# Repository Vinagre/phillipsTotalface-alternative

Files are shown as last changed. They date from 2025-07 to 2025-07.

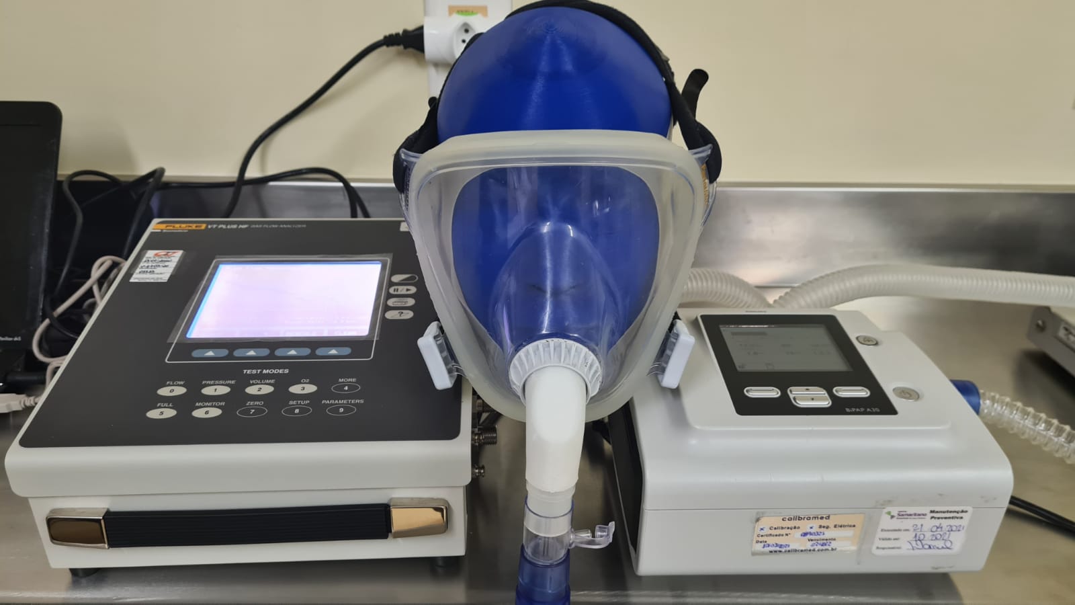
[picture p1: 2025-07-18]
images/test-setupo-02.jpeg

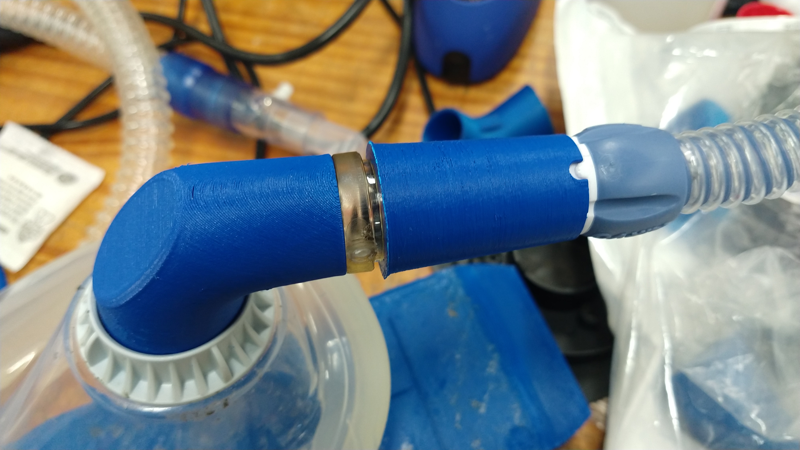
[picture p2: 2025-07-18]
images/testing.jpg

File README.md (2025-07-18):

 
# Manufatura Aditiva para Resiliência em Saúde  
# Additive Manufacturing for Healthcare Resilience

**Autores / Authors:**  
Raphael Vinagre, Marcelo Viana Marques Ferreira, João Victor Correia de Melo, Jorge Roberto Lopes

**Descrição / Description**  
Desenvolvimento, validação e documentação de dispositivos médicos impressos em 3D para ventilação não-invasiva em cenários de crise.  
Development, validation, and documentation of 3D-printed medical devices for non-invasive ventilation in crisis scenarios.

O projeto adota uma abordagem de design centrada no usuário e produção distribuída, promovendo resiliência hospitalar e manufatura aberta.  
The project adopts a human-centered design and distributed manufacturing, fostering hospital resilience and open manufacturing.

**Estrutura / Structure**
- `/stl/`: Arquivos STL das peças / STL 3D model files
- `/testes/`: Relatórios e dados experimentais / Test reports and raw data
- `/docs/`: Metodologia e fichas técnicas / Methodology and technical datasheets

**Licenciamento / Licensing**  
CC BY-SA 4.0. Consulte LICENSE / See LICENSE

---

Repositório bilíngue. Para informações detalhadas, consultar cada subdiretório.  
Bilingual repository. For detailed information, check each subdirectory.
=======
# phillipsTotalface-alternative
Development, validation, and documentation of 3D-printed medical devices for non-invasive ventilation in crisis scenarios. The project adopts a human-centered design approach and explores distributed production of critical components to enhance hospital resilience

# Manufatura Aditiva para Resiliência em Saúde  
# Additive Manufacturing for Healthcare Resilience

**Autores / Authors:**  
Raphael Vinagre, Marcelo Viana Marques Ferreira, João Victor Correia de Melo, Jorge Roberto Lopes

**Descrição / Description**  
Desenvolvimento, validação e documentação de dispositivos médicos impressos em 3D para ventilação não-invasiva em cenários de crise.  
Development, validation, and documentation of 3D-printed medical devices for non-invasive ventilation in crisis scenarios.

O projeto adota uma abordagem de design centrada no usuário e produção distribuída, promovendo resiliência hospitalar e manufatura aberta.  
The project adopts a human-centered design and distributed manufacturing, fostering hospital resilience and open manufacturing.

**Estrutura / Structure**
- `/stl/`: Arquivos STL das peças / STL 3D model files
- `/testes/`: Relatórios e dados experimentais / Test reports and raw data
- `/docs/`: Metodologia e fichas técnicas / Methodology and technical datasheets

**Licenciamento / Licensing**  
CC BY-SA 4.0. Consulte LICENSE / See LICENSE

---

Repositório bilíngue. Para informações detalhadas, consultar cada subdiretório.  
Bilingual repository. For detailed information, check each subdirectory.

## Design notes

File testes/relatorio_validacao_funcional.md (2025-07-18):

# Relatório de Validação Funcional  
# Functional Validation Report

**Autores / Authors:**  
Raphael Vinagre, Marcelo Viana Marques Ferreira, João Victor Correia de Melo, Jorge Roberto Lopes

## Amostragem / Sampling
- 30 unidades impressas (ABS) / 30 printed units (ABS)
- 10 unidades originais (controle, Philips) / 10 original units (control, Philips)

## Variáveis Testadas / Variables Tested
- Vedação / Seal integrity
- Resistência mecânica / Mechanical resistance
- Estabilidade dimensional pós-esterilização / Dimensional stability after sterilization

## Resultados / Results
- Diferença de pressão máxima: 2,1% (dentro da margem ISO 80601-2-12:2020)  
  Max pressure difference: 2.1% (within ISO 80601-2-12:2020 margin)
- Vedação equivalente em 98% dos testes  
  Equivalent sealing in 98% of tests
- Aceitação clínica: 100% na simulação  
  Clinical acceptance: 100% in simulation

*Detalhes quantitativos estão em `tabela_resultados.csv`.*  
*See `tabela_resultados.csv` for quantitative details.*

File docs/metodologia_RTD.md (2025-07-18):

# Metodologia Research Through Design (RTD)  
# Research Through Design (RTD) Methodology

**Autores / Authors:**  
Raphael Vinagre, Marcelo Viana Marques Ferreira, João Victor Correia de Melo, Jorge Roberto Lopes

## O que é RTD?  
A Research Through Design integra pesquisa e prática de projeto em ciclos iterativos, gerando soluções técnica e socialmente viáveis.  
Research Through Design (RTD) integrates research and design practice in iterative cycles, generating technically and socially viable solutions.

## Aplicação no projeto / Application in the project
- Imersão clínica / Clinical immersion
- Co-design interdisciplinar / Interdisciplinary co-design
- Prototipagem e testes iterativos / Iterative prototyping and testing
- Avaliação empírica e otimização final / Empirical evaluation and final optimization

*Veja documento principal para fluxograma detalhado.*  
*See main report for detailed flowchart.*

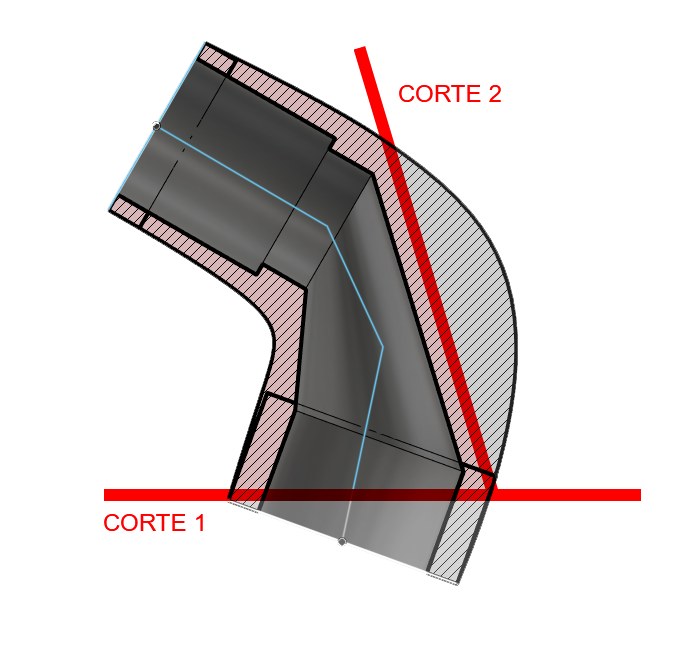
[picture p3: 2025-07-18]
images/cortes-peca.png

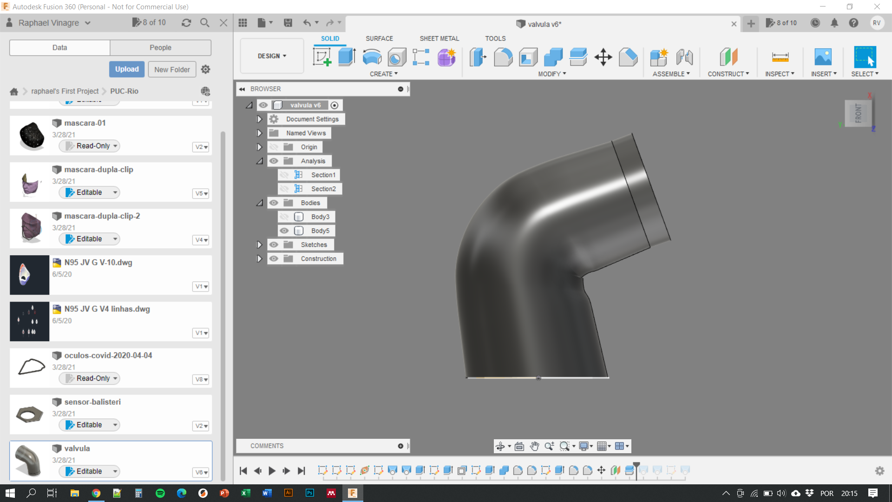
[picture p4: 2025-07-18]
images/fusion-drawing.png

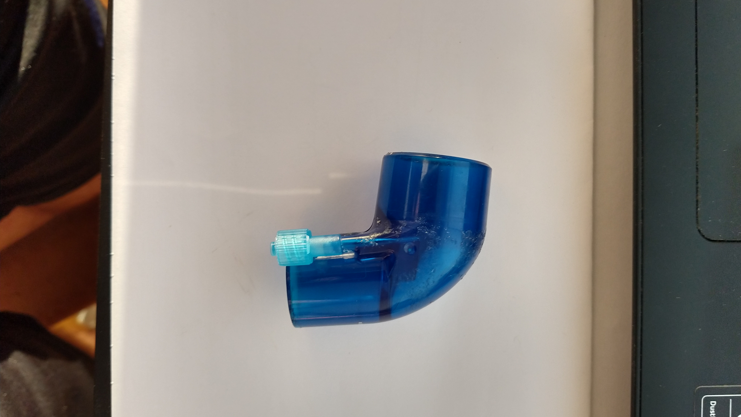
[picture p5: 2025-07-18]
images/IMG_20210326_170816761_HDR.jpg

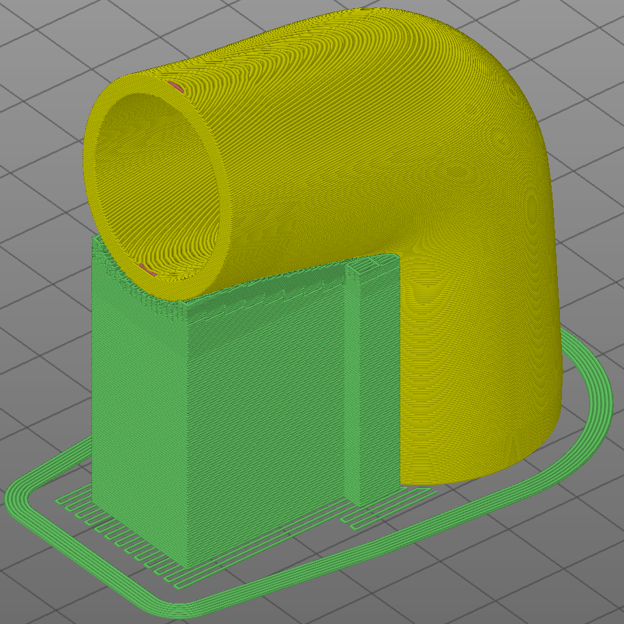
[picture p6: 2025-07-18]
images/suportes.png

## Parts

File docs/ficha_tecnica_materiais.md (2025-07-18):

# Ficha Técnica – Polímero ABS para Impressão 3D  
# ABS Polymer Technical Datasheet for 3D Printing

**Autores / Authors:**  
Raphael Vinagre, Marcelo Viana Marques Ferreira, João Victor Correia de Melo, Jorge Roberto Lopes

| Parâmetro | Valor (PT) | Value (EN) |
|---|---|---|
| Temp. bico | 220°C ± 5°C | Nozzle temp |
| Temp. mesa | 110°C ± 2°C | Bed temp |
| Velocidade impressão| 60 mm/s | Print speed |
| Esp. parede | 1,6 mm | Wall thickness |
| Altura de camada | 0,2 mm | Layer height |
| Preenchimento | 100% | Infill |
| Resfriamento | Desligado | Cooling off |

**Observação / Note:**  
ABS recomendado pela estabilidade após esterilização em vapor e peróxido.  
ABS is recommended due to its stability after vapor and hydrogen peroxide sterilization.

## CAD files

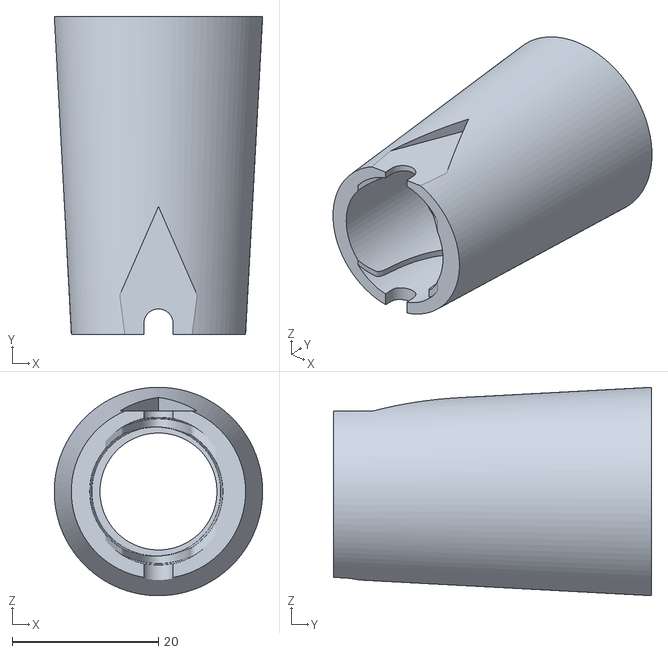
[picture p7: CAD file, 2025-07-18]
stl/encaixe-universalx-v5.stl
28.5 x 43.5 x 28.5

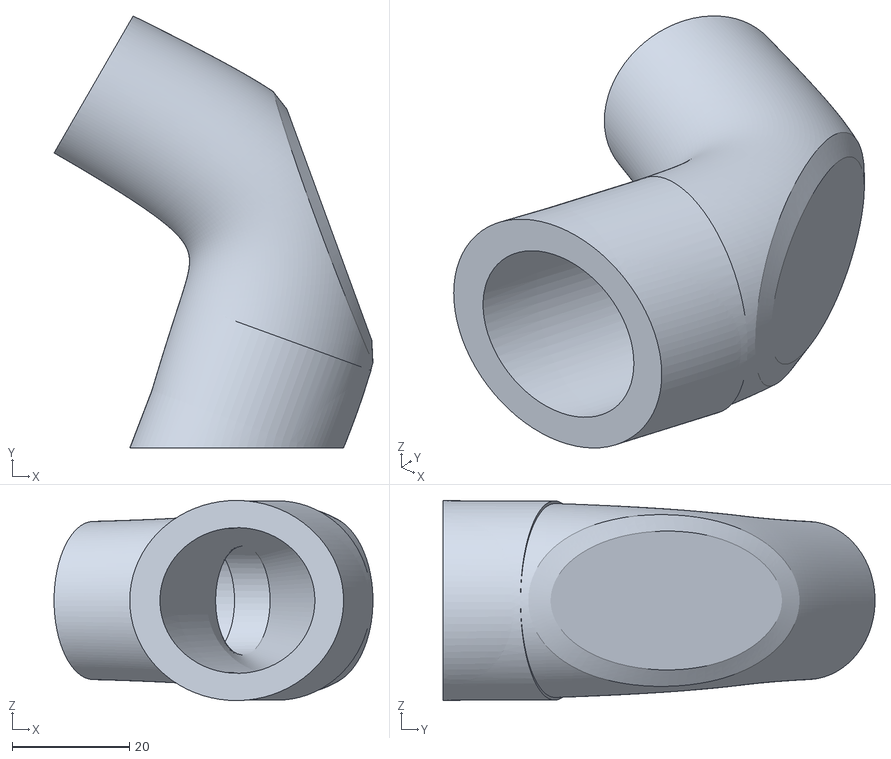
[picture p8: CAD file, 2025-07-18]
stl/conexao-respirador.stl
54.4 x 73.7 x 34.1

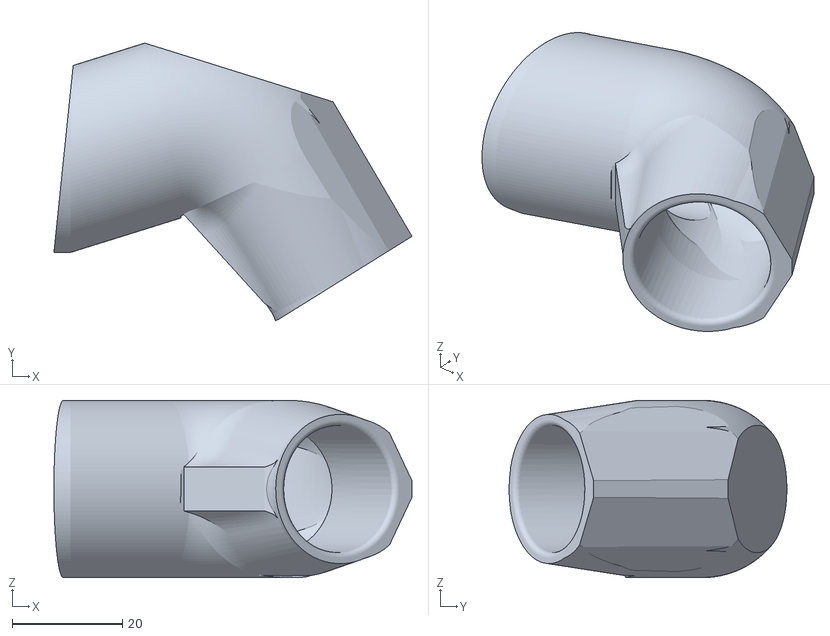
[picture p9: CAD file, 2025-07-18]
stl/joelho-encaixe-2022.stl
64.8 x 50.3 x 32.1

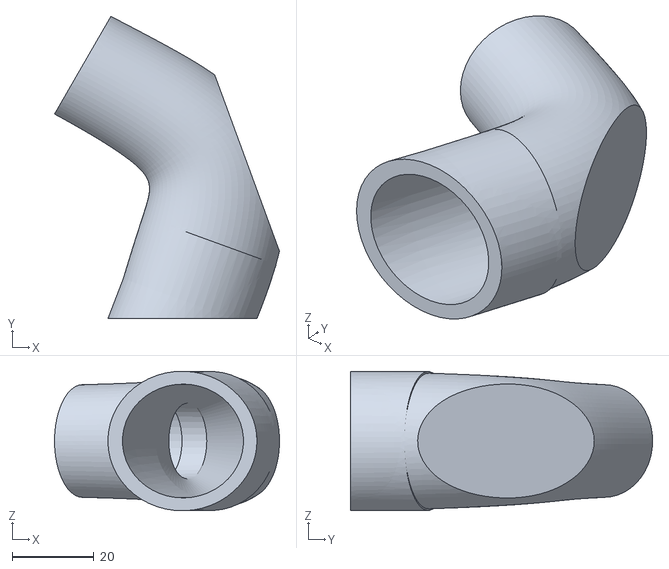
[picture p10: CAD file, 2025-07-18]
stl/conexao-respirador v5.stl
55.1 x 74.0 x 34.1

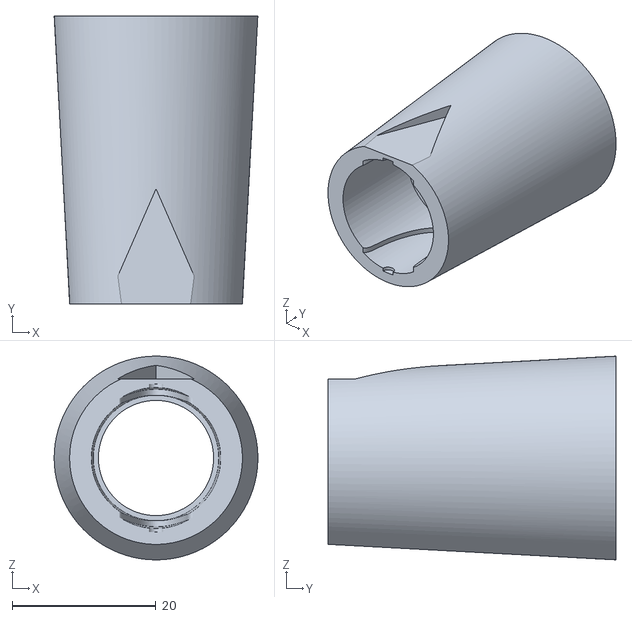
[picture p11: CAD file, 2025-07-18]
stl/encaixe-universalx.stl
28.3 x 40.0 x 28.3

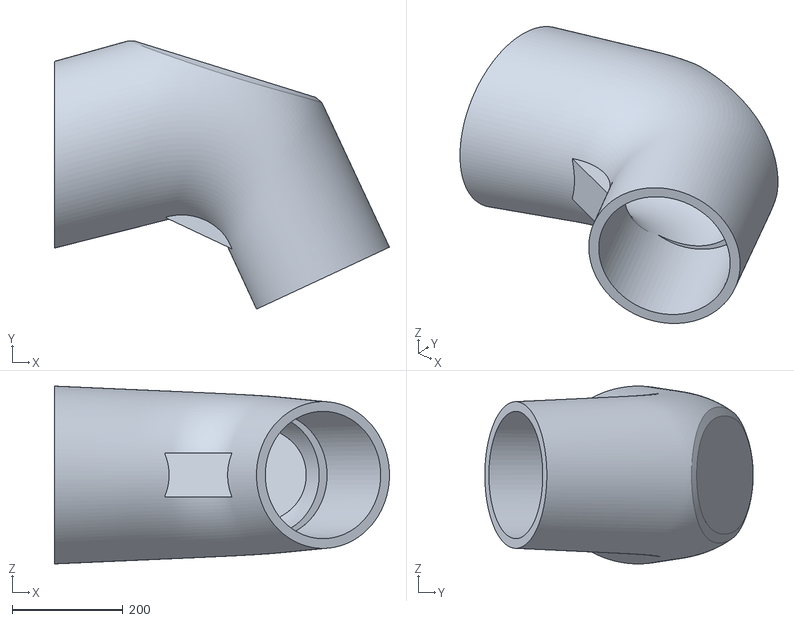
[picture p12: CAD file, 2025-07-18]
stl/conector-J-v2.stl
605.0 x 484.6 x 321.2

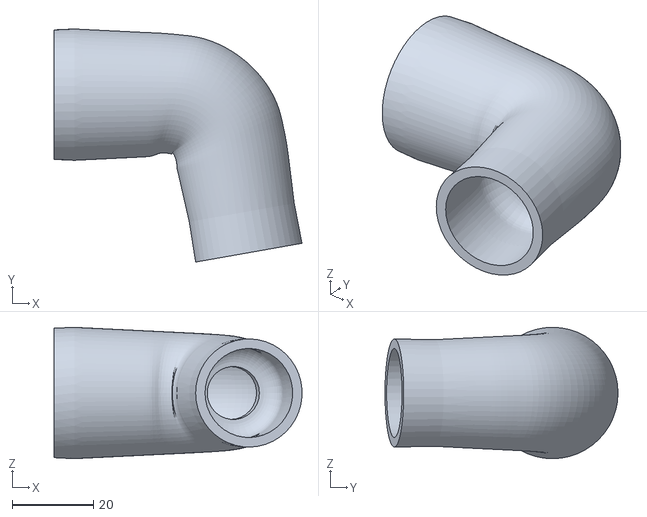
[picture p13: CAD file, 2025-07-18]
stl/joelho-respirador-v7.stl
60.9 x 57.2 x 32.2

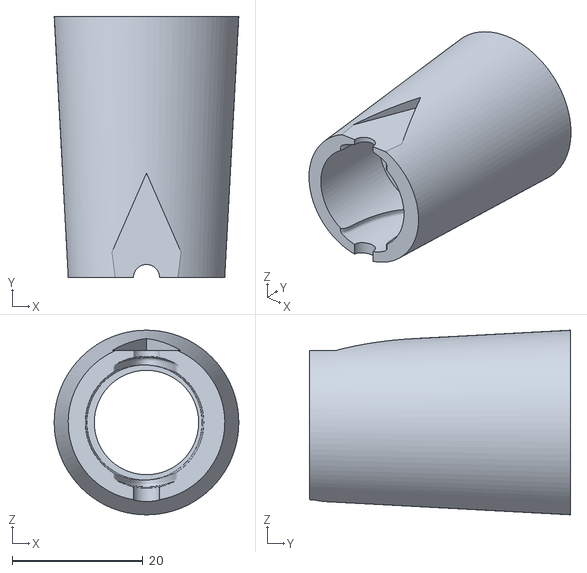
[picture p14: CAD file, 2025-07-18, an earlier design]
stl/encaixe-universalx-v4.stl
28.3 x 40.0 x 28.3

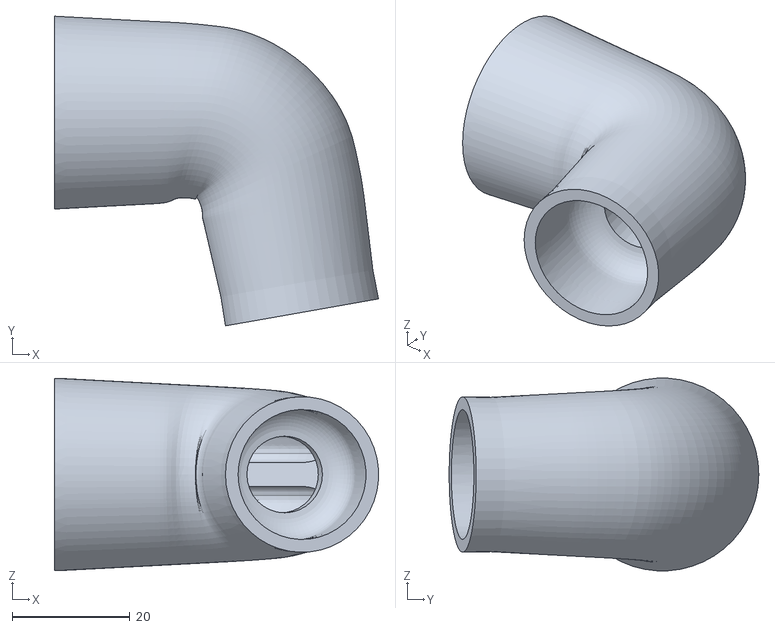
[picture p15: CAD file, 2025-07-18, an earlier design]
stl/joelho-respirador-v2.stl
54.9 x 52.5 x 32.6

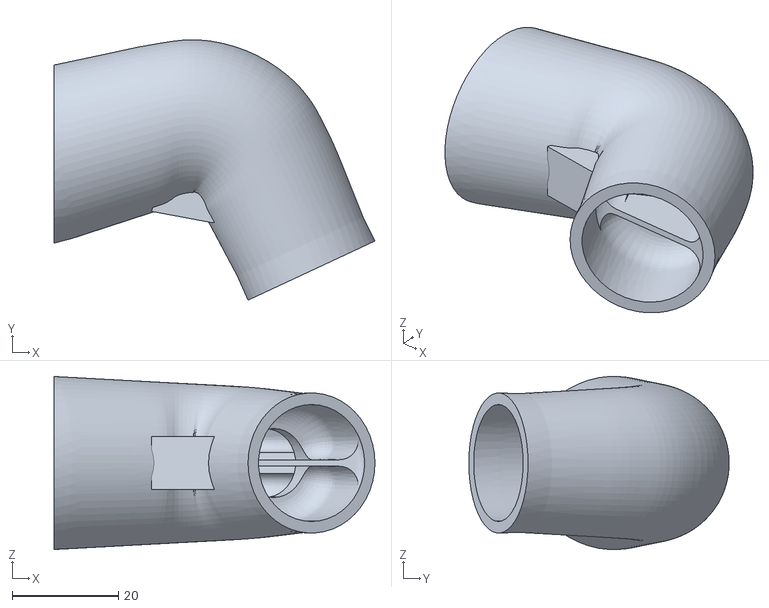
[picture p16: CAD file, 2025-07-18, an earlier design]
stl/joelho-respirador-v6.stl
60.4 x 49.0 x 32.6

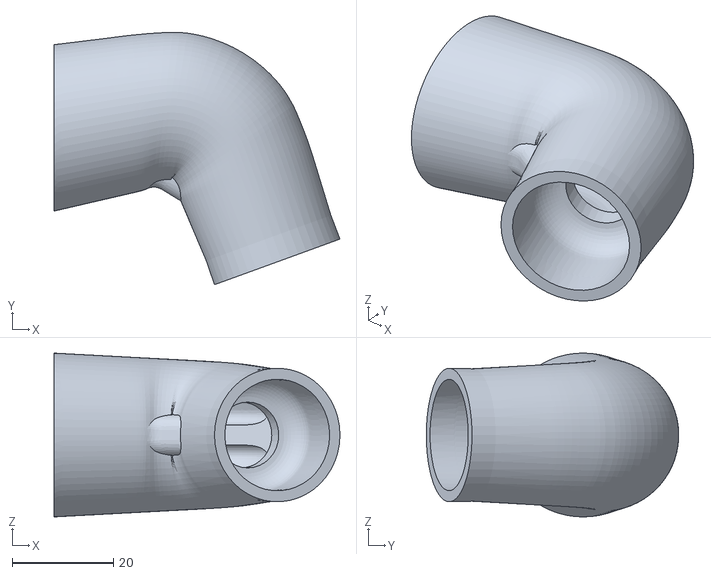
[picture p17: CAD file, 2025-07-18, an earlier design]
stl/joelho-respirador-v3.stl
56.5 x 49.8 x 32.4

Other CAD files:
stl/conexao-respirador v2.stl
stl/encaixe-universalx-v2.stl
stl/encaixe-universalx-v3.stl
stl/joelho-respirador-v5.stl
stl/conexao-respirador v4.stl

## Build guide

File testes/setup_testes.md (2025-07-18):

# Setup Experimental dos Testes  
# Test Experimental Setup

**Autores / Authors:**  
Raphael Vinagre, Marcelo Viana Marques Ferreira, João Victor Correia de Melo, Jorge Roberto Lopes

## Objetivo / Objective  
Descrever o ambiente, instrumentos e procedimentos empregados na validação funcional dos conectores impressos em 3D.  
Describe the environment, instruments, and procedures used in the functional validation of the 3D-printed connectors.

## Equipamentos / Equipment
- Analisador de fluxo: VT PLUS HF (Fluke)
- Sistema de aquisição: LabView 2021 + DAQ NI-9215
- Pulmão artificial: Test Lung 6810 (Dräger)
- Câmara climática: Binder BD56

## Protocolo / Protocol
1. Montar o conector impresso à máscara VNI e circuito do ventilador.  
   Attach the printed connector to the NIV mask and ventilator circuit.
2. Realizar 5 medições por unidade, monitorando pressão, vazão e vedação.  
   Perform 5 measurements per unit; monitor pressure, flow, and sealing.
3. Registrar dados em planilha CSV.  
   Record data in CSV spreadsheet.

*Para resultados quantitativos, consulte `tabela_resultados.csv`.*  
*For quantitative results, see `tabela_resultados.csv`.*

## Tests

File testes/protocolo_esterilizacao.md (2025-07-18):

# Protocolo de Esterilização  
# Sterilization Protocol

**Autores / Authors:**  
Raphael Vinagre, Marcelo Viana Marques Ferreira, João Victor Correia de Melo, Jorge Roberto Lopes

## Materiais Testados / Materials Tested
- ABS virgem e reciclado, PLA, PETG, Nylon, Resina SLA  
  Virgin and recycled ABS, PLA, PETG, Nylon, SLA resin

## Métodos / Methods
1. Autoclave (calor úmido, 121ºC, 20min)  
   Autoclave (moist heat, 121ºC, 20min)
2. Sterrad (peróxido de hidrogênio)  
   Sterrad (hydrogen peroxide vapor)

## Observações / Notes
- ABS: estável após 10 ciclos Sterrad.  
  ABS: stable after 10 Sterrad cycles.
- PLA/PETG: falha após 2 ciclos.  
  PLA/PETG: failed after 2 cycles.

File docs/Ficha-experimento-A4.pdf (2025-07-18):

# Ficha de Experimento

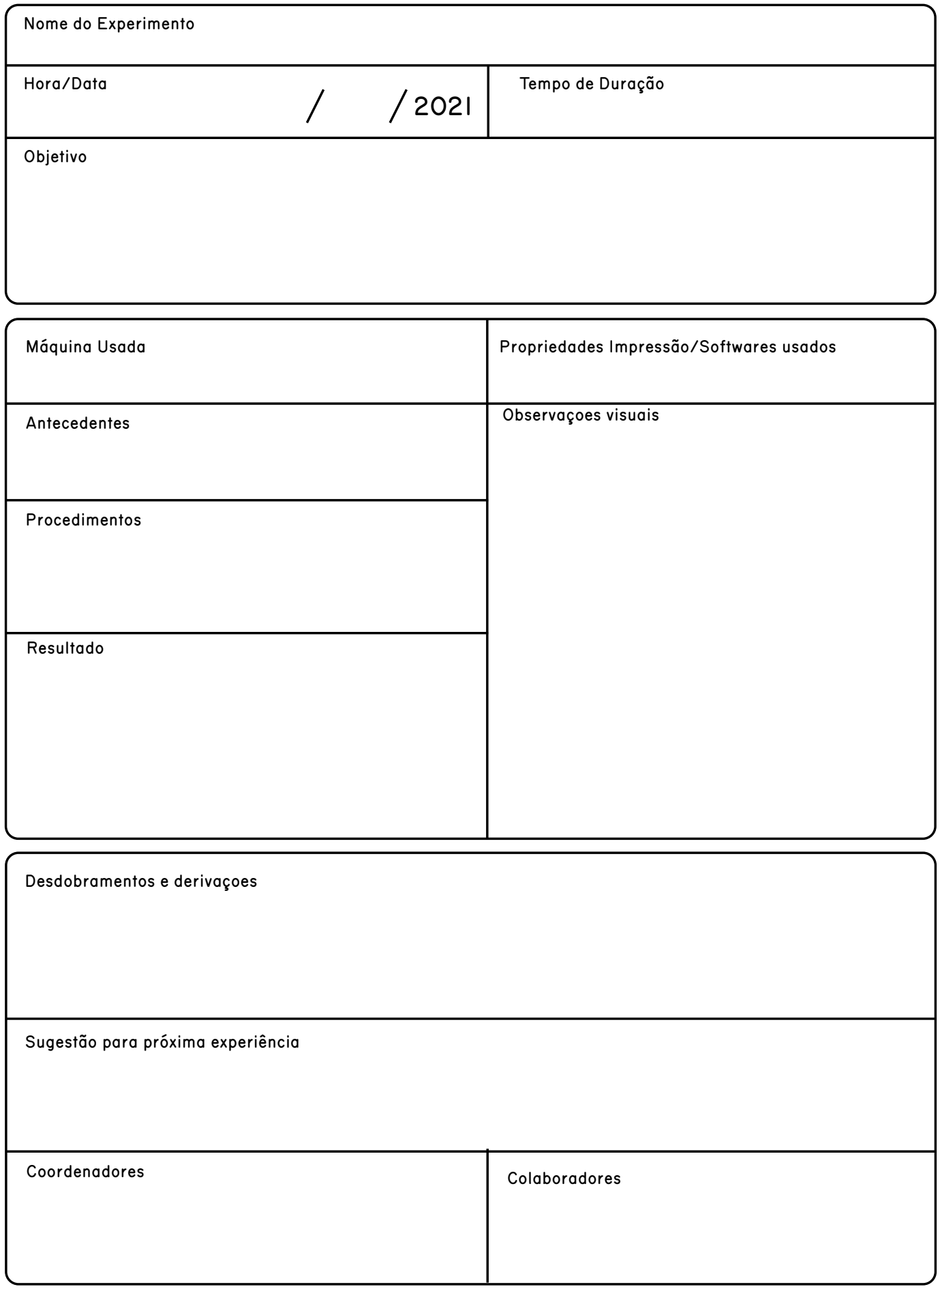
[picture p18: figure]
Nome do Experimento; Hora/Data; Objetivo; Tempo de Duração; Coordenadores; Colaboradores; Antecedentes; Máquina Usada; Propriedades Impressão/Softwares usados; Resultado; Observações visuais; Sugestão para próxima experiência; Desdobramentos e derivações; Procedimentos
